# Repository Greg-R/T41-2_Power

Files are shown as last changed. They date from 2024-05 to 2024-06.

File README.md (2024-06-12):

# T41-2 Power Supply Module Version 1.0

This is the PCB for the improved Power Supply module for the T41 "Software Defined Transceiver".
The PCB was designed using the open-source design tool Kicad 8.  The github repository is here:

<https://github.com/Greg-R/T41-2_Power>

The primary documentation for the T41 is the book "Digital Signal Processing and Software Defined Radio:
Theory and Construction of the T41-EP Software Defined Transceiver Third Edition" by Albert Peter and Jack Purdum.
The book is available here:

<https://www.amazon.com/Digital-Signal-Processing-Software-Defined/dp/B0D25FV48C>

The goal of the T41-2 Power supply module is to decrease current drain and dissipated power.  
The original V10 power supply uses linear regulators for the 3.3 and 5.0 volt supplies with +12 volts input.
This dissipates a large amount of power in the regulators.  The regulator devices get very
hot!  This excess power dissipation increases the receiver current drain by a factor of two
compared to the T41-2!  That is a serious problem when operating portable from a battery supply.

The vast majority of the T41 current drain during receive is due to the Teensy and the display.
As the T41 evolves, more features included in the software means Teensy power consumption is
going to increase.  Also some builders are planning to use larger displays, thus increasing
current drain and regulator dissipation even more.  Watch out, your fingers are in danger!

The T41-2 Power Supply solves this problem by using the ingenious switching power supply modules by Recom:

<https://recom-power.com/pdf/Innoline/R-78CK-0.5.pdf>

A concern is noise and interference generated by the switching power supply circuits.  All modern radios use
switching power supplies and deal with these problems via appropriate PCB layout and decoupling.  The T41-2
Power Supply is adequately decoupled, and testing so far has not revealed detectable noise from the switching
circuits.  Other circuits in the radio, primarily the Teensy and especially the display, tend to dominate the
internally generated noise.

## 5 Volt Display Power Output

Another noise reduction feature of the T41-2 Power Supply is the +5 volt output for the display.  Past
experiments have demonstrated a reduction in receiver noise by switching the display to 5 volts and routing
the 5 volt supply directly to the display rather than through the Main board.  If this is attempted, the
builder is advised to refer to the display's manual to understand the change necessary to power the display
from 5 volts rather than the as-shipped 3.3 volts.  A means of routing the 5 volts to the display must be
devised, which means adding wires and cutting the 3.3 volt supply from the Main board.

## Gerber Files and PDF Schematic

Gerber files for PCB fabrication are included in the gerbers folder:

<https://github.com/Greg-R/T41-2_Power/tree/main/gerber>

A PDF of the schematic (T41-2_Power.pdf) is included for quick viewing of the circuit design:

<https://github.com/Greg-R/T41-2_Power/blob/main/doc/T41-2_Power.pdf>

## Speaker Output Terminal

A convenience feature of the board is a terminal for the speaker outputs.  The speaker output from the Main
board is routed via the 16-pin ribbon cable.  However there was no plug or jack connected to these wires.
Since the board has the common 16-pin connector, it is possible to route the speaker outputs to a terminal.
This is an improvement, as the board can be removed from the radio without having to unsolder the speaker wires.

### Hardware Modifications

If you don't want to convert the display to 5 volts, the board will drop-in.  Please refer to the display
documentation for 5 volt conversion instructions if you desire to make this modification.  You will have to
solder wires to either the Main board or display in order to connect to the 5 volt output of the power supply.

There is no modification required to the software.

### PCB Layout

The PCB layout was completed using Kicad version 8.  This is an open-source tool, unlike the "Dip Trace" commercial product used
to design the V010 and other T41 boards.

The prototype PCBs were fabricated by PCBWay at a cost of US$1.00 each.  Shipping was about US$25.00 for quantity 5 boards.

## Bill Of Material (BOM)

A public Digikey BOM is here:

<https://www.digikey.com/en/mylists/list/PVESXUZZUA>

Please use the special low ESR/ESL bypass capacitors as specified in the BOM.  These parts improve the bypassing
and decoupling of the switching power supply modules.

## Build Tips

In general, T41-2 Power Supply is easy to build if you have experience with surface-mount components.

### Ferrite Beads and Large Diode

The circuit uses several large ferrite beads, and one single large surface mount diode.  I was able to solder these
using regular solder paste and hot air gun.  It requires a little more "dwell time" to get these large parts soldered.

### Surface Mount Electrolytics

It may be easier to use a soldering iron for the surface mount electroytics.  I was able to use the hot air gun
successfully.  However, I did melt the plastic base on these parts a little bit.  That didn't cause any damage, apparently.

### 3D Printed Bracket

The 3D printed bracket is the same as the original Power Supply bracket.  I have a repository with many files for T41 parts:

<https://github.com/Greg-R/SDT_Case_KF5N>

### Bottom Side Parts

There are a few parts on the bottom side.  These should be soldered after the top-side SMDs.  I was able to use a hot air gun without any of the top-side components desoldering.

### Through-Hole Parts

Solder the 16 pin connector and the through-hole terminals last.

### High Resolution Photos of T41-2 Power Supply

Links to photos of a fully constructed T41-2 Power Supply follow.

<https://drive.google.com/file/d/1z1g1Ql-YoIg5F6N_AF6bPJcIj28t9C05/view?usp=sharing>

<https://drive.google.com/file/d/1M7f0Y-oaXFjQSSRTwqgoiVwlohlh6RSp/view?usp=sharing>

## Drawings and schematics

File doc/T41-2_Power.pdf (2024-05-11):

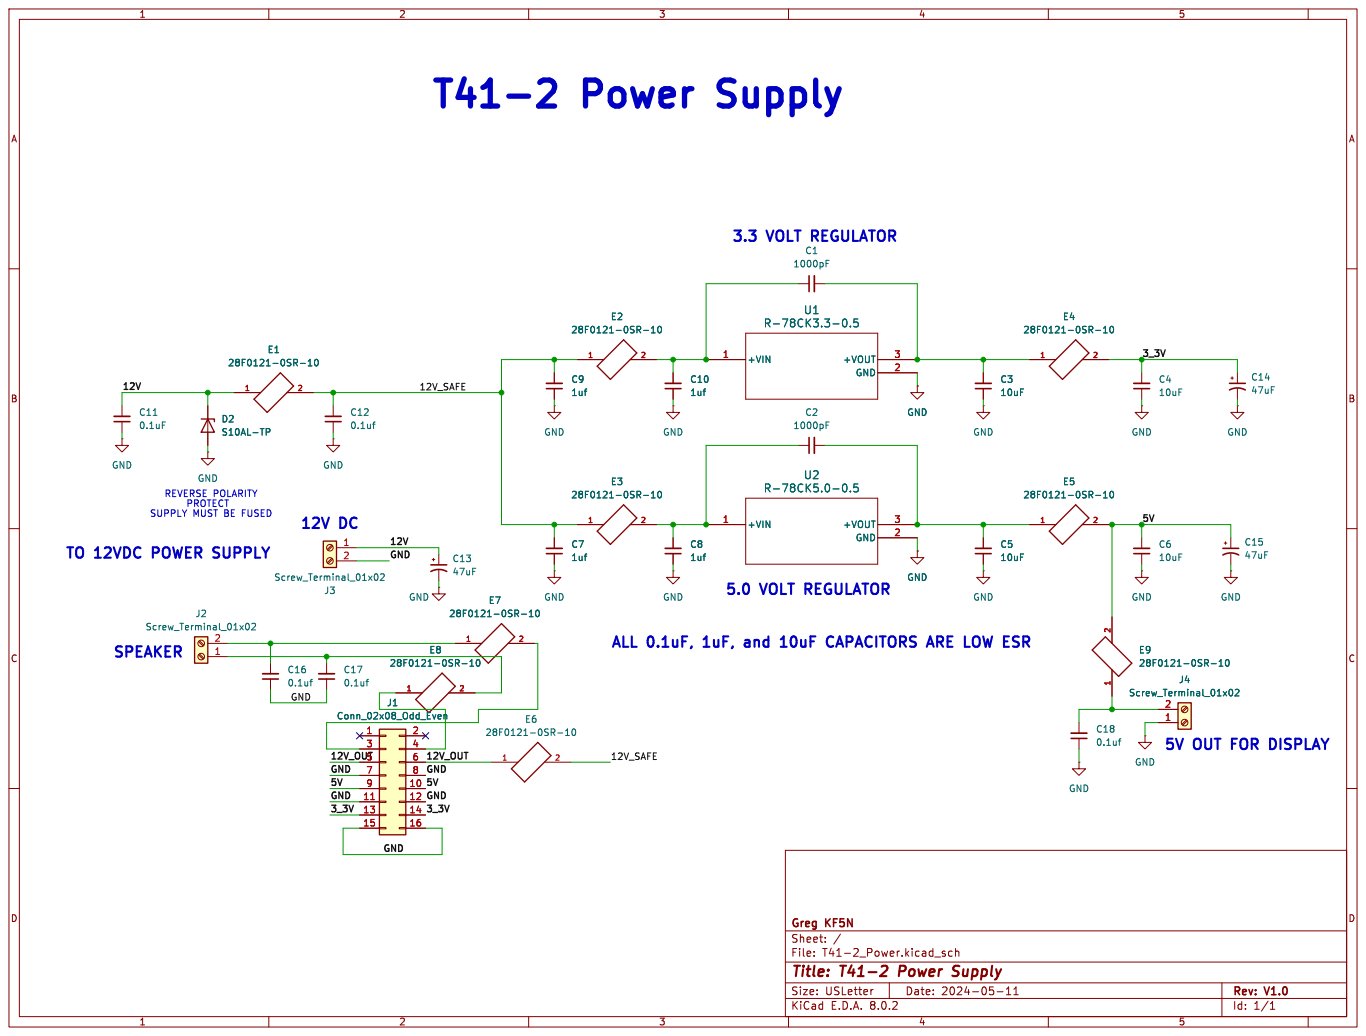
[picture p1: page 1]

SUPPLY MUST BE FUSED SPEAKER

12V_SAFE ALL 0.1uF, 1uF, and 10uF CAPACITORS ARE LOW ESR

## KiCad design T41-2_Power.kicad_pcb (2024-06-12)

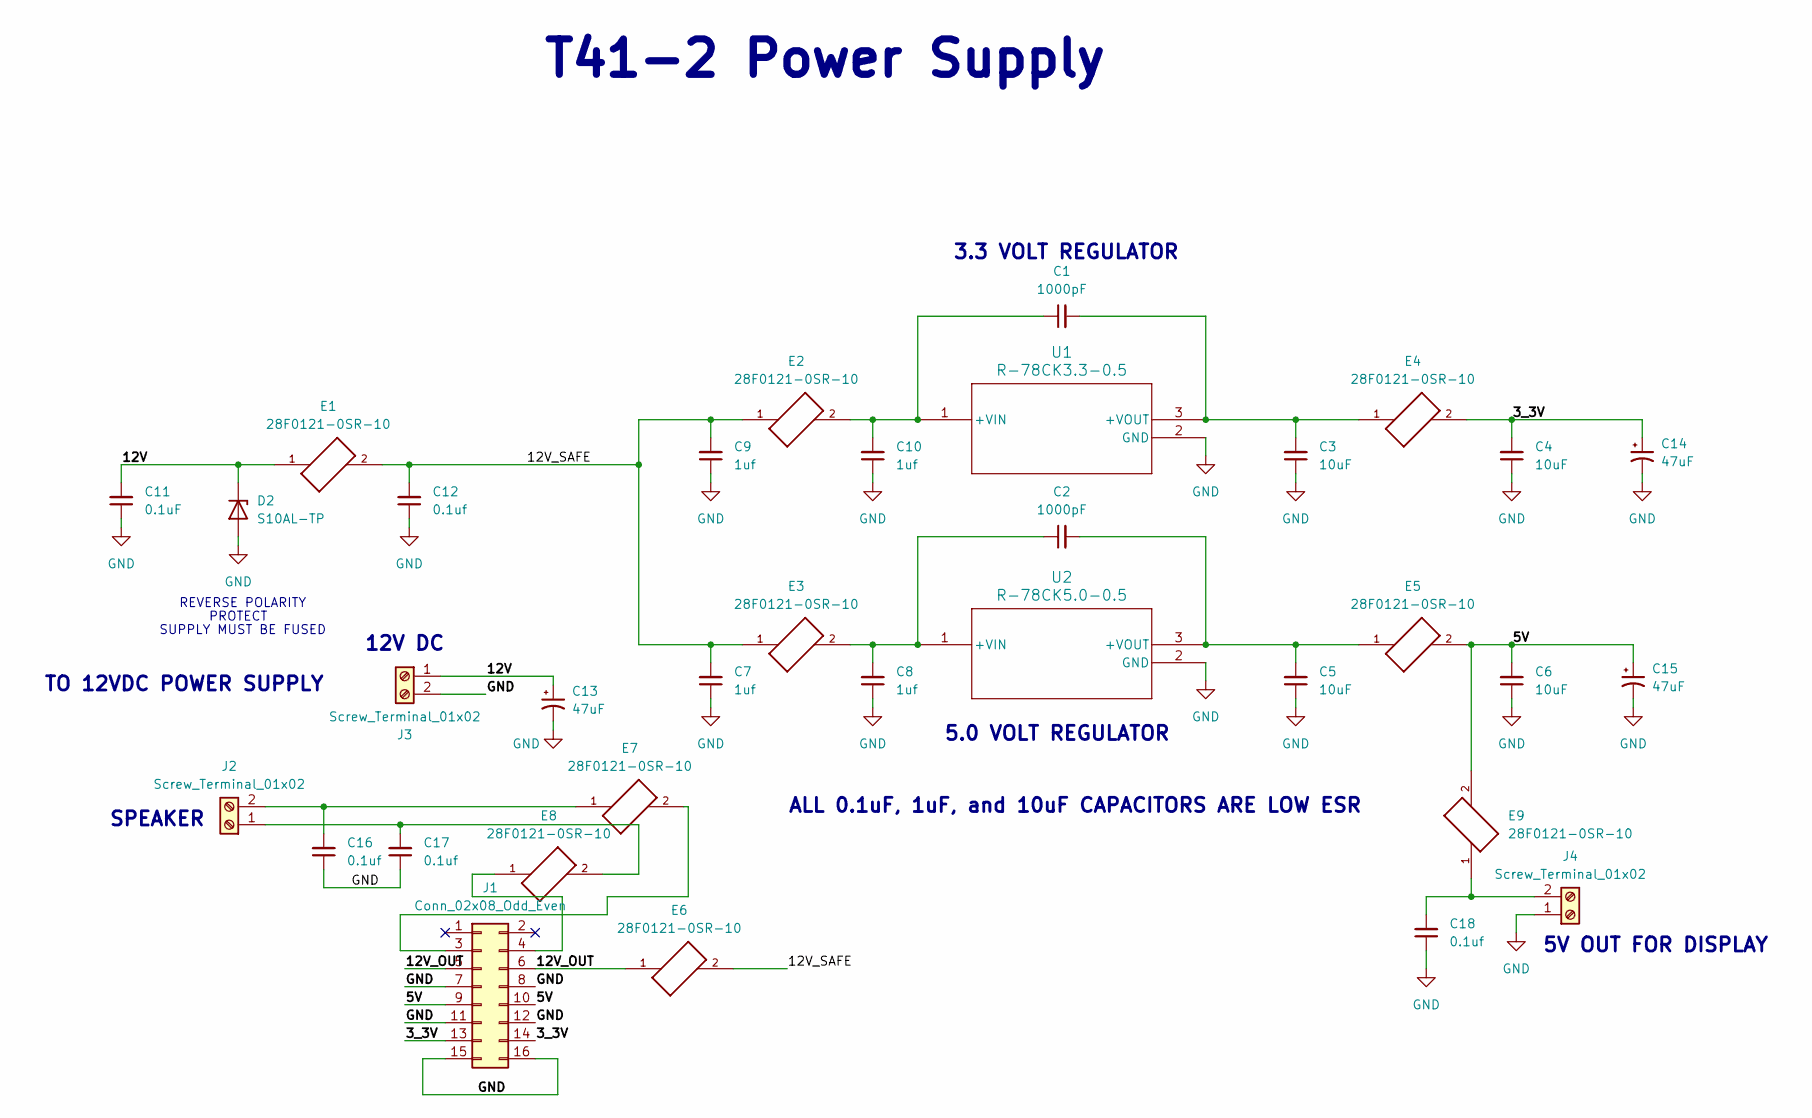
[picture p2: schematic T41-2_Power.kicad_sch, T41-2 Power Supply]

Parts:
C1, C2: 1000pF; C_1206_3216Metric
C3, C4, C5, C6: 10uF; C_1206_3216Metric
C7, C8, C9, C10: 1uf; C_1206_3216Metric
C11: 0.1uF; C_1206_3216Metric
C12, C16, C17, C18: 0.1uf; C_1206_3216Metric
C13, C14, C15: 47uF; CP_Elec_6.3x5.7
D2: S10AL-TP; D_SMC
E1, E2, E3, E4, E5, E6, E7, E8, E9: 28F0121-0SR-10; FB_28F0121-0SR-10; PARTREV J
J1: Conn_02x08_Odd_Even; IDC-Header_2x08_P2.54mm_Vertical
J2, J3, J4: Screw_Terminal_01x02; TerminalBlock_Philmore_TB132_1x02_P5.00mm_Horizontal
U1: R-78CK3.3-0.5; CONV_R-78CK5.0-0.5
U2: R-78CK5.0-0.5; CONV_R-78CK5.0-0.5

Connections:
/3_3V: C4.2, C14.1, E4.2, J1.13, J1.14
/5V: C6.2, C15.1, E5.2, E9.2, J1.9, J1.10
/12V: C11.2, C13.1, D2.1 (K), E1.1, J3.1
/12V_OUT: E6.1, J1.5, J1.6
/12V_SAFE: C7.2, C9.2, C12.2, E1.2, E2.1, E3.1, E6.2
GND: C3.1, C4.1, C5.1, C6.1, C7.1, C8.1, C9.1, C10.1, C11.1, C12.1, C13.2, C14.2, C15.2, C16.1, C17.1, C18.1, D2.2 (A), J1.7, J1.8, J1.11, J1.12, J1.15, J1.16, J3.2, J4.1, U1.2 (GND), U2.2 (GND)
unnamed: E7.2, J1.3
unnamed: E8.1, J1.4
unnamed: C17.2, E8.2, J2.1
unnamed: C16.2, E7.1, J2.2
unnamed: C18.2, E9.1, J4.2
unnamed: C1.1, C10.2, E2.2, U1.1 (+VIN)
unnamed: C1.2, C3.2, E4.1, U1.3 (+VOUT)
unnamed: C2.1, C8.2, E3.2, U2.1 (+VIN)
unnamed: C2.2, C5.2, E5.1, U2.3 (+VOUT)

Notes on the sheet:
SUPPLY MUST BE FUSED
SPEAKER
T41-2 Power Supply
3.3 VOLT REGULATOR
ALL 0.1uF, 1uF, and 10uF CAPACITORS ARE LOW ESR
12V DC
REVERSE POLARITY
5V OUT FOR DISPLAY
PROTECT
TO 12VDC POWER SUPPLY
5.0 VOLT REGULATOR

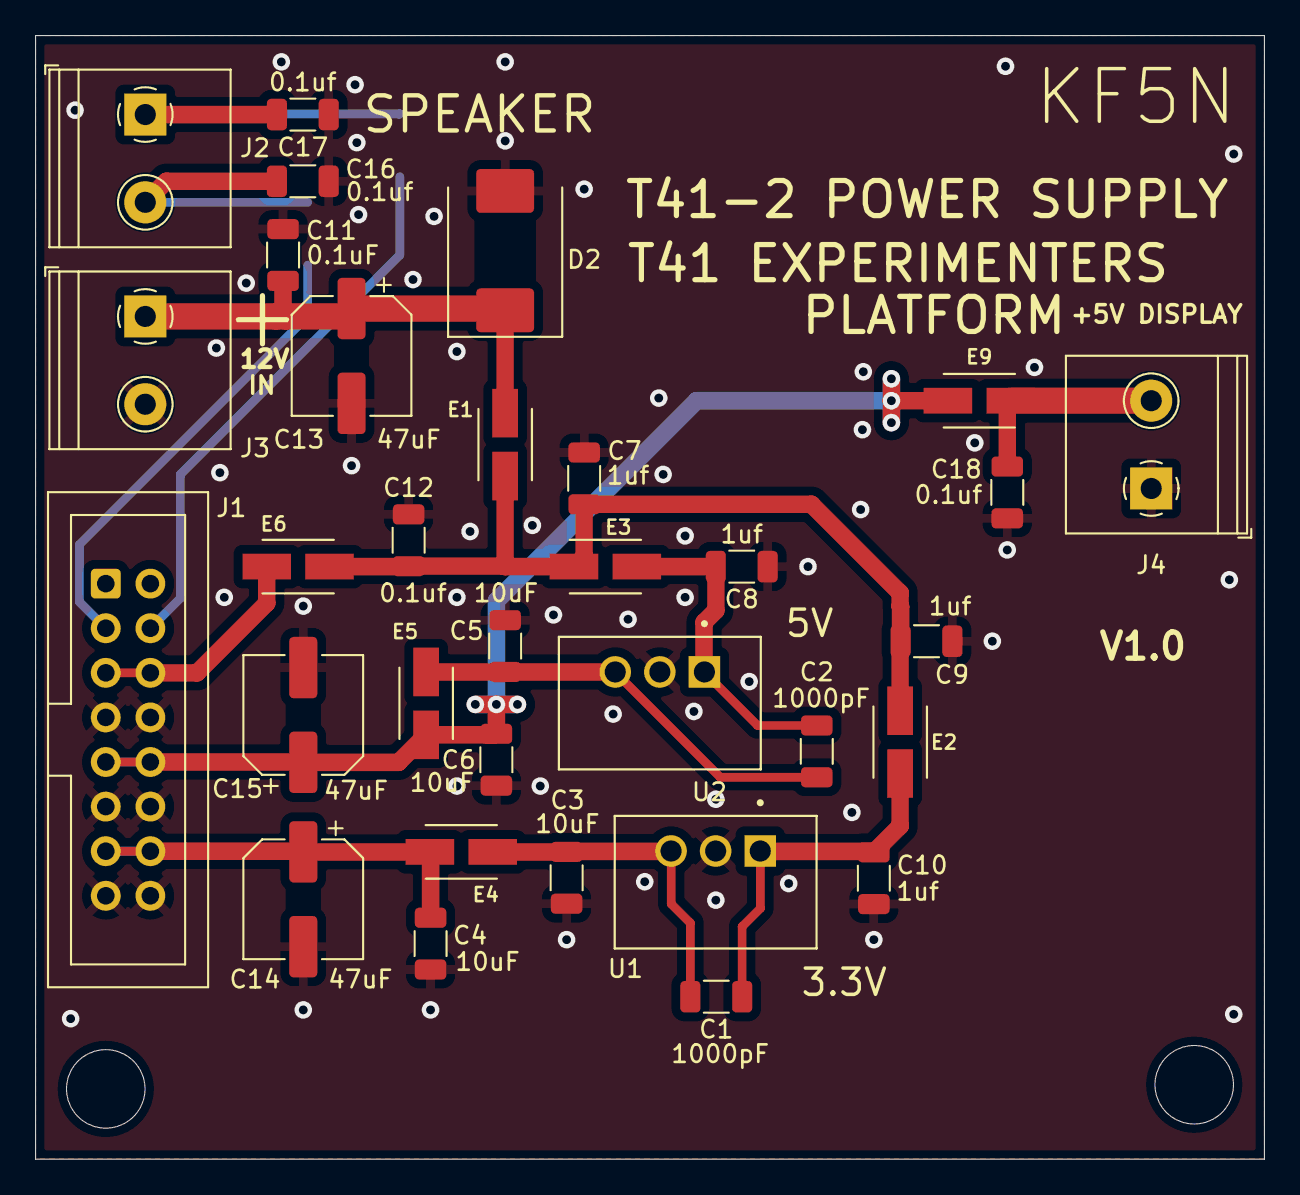
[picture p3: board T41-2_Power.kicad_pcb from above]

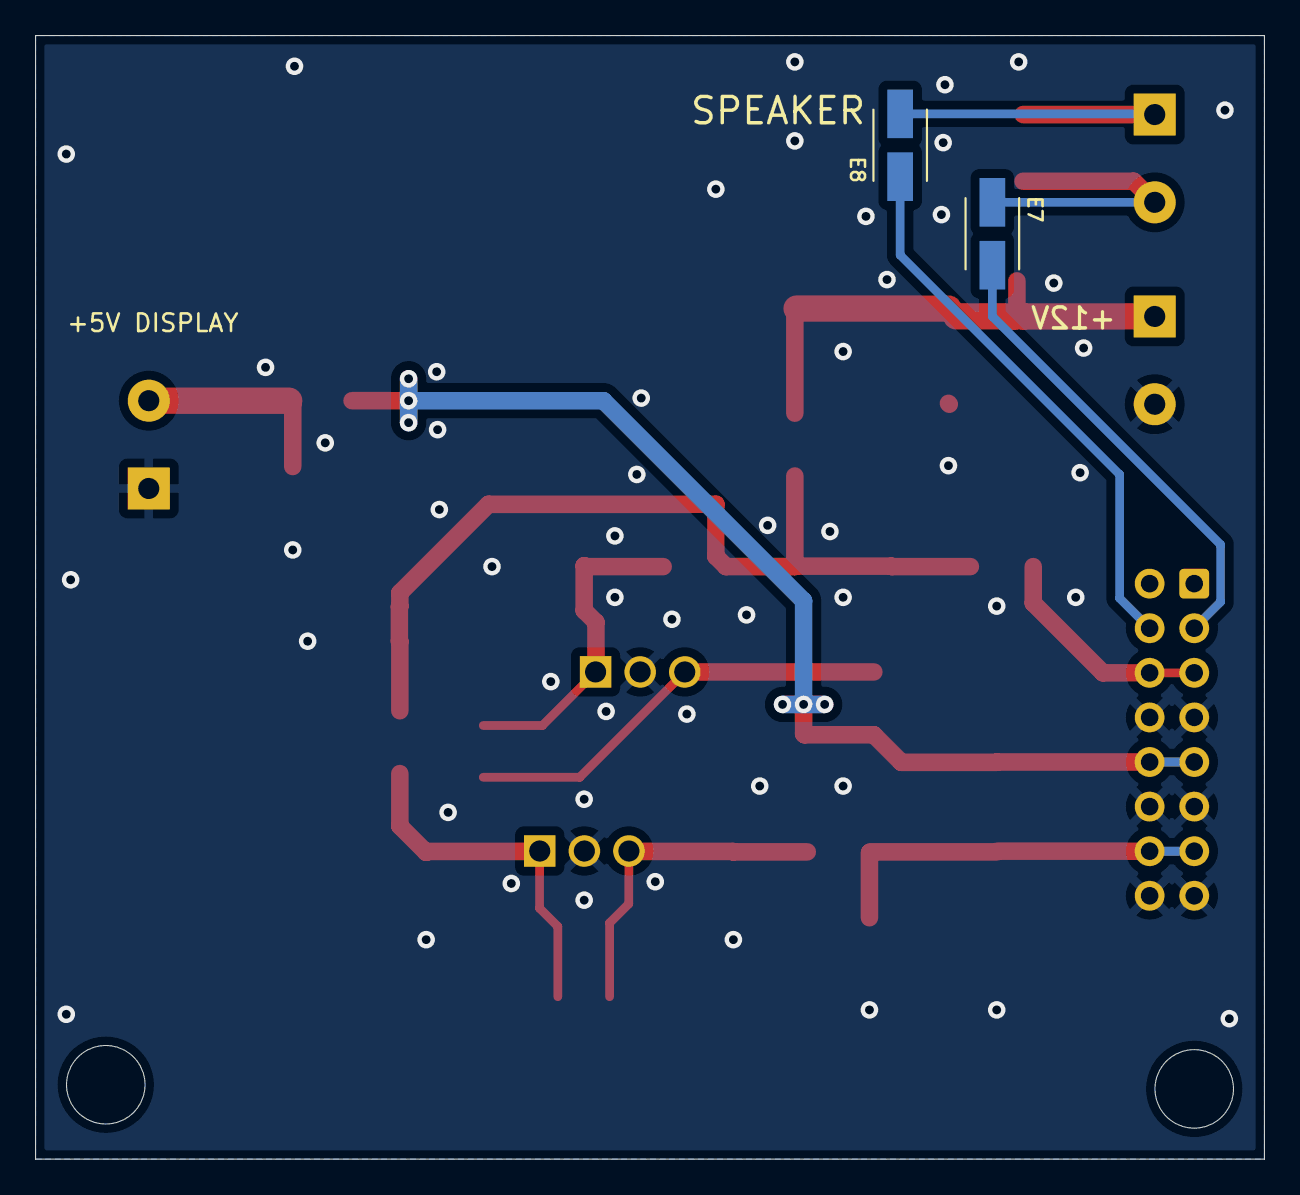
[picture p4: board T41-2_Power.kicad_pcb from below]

Board: 2 copper layers, 70.0 x 64.0 mm, 34 parts (2 on the bottom side), 15 nets.

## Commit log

2024-05-11 Added 5V outlet for display power.
    [T41-2_Power.kicad_pcb, T41-2_Power.kicad_sch]
2024-05-11 Updated PDF schematic.
    [T41-2_Power.kicad_sch]
2024-05-11 Updated gerbers, ready for fab V1.0.
    [T41-2_Power-B_Cu.gbr, T41-2_Power-B_Mask.gbr, T41-2_Power-B_Silkscreen.gbr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]
2024-06-12 Added + indicator in silkscreen for 5V output.
    [T41-2_Power-B_Cu.gbr, T41-2_Power-B_Mask.gbr, T41-2_Power-B_Silkscreen.gbr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]
2026-04-22 Updated schematic with note on V10/V11 versus T41-2 speaker connection.
2026-08-05 Upgraded to new Kicad version.
2026-08-11 T41-3 power supply modified to have audio amplifier output instead of speaker.
